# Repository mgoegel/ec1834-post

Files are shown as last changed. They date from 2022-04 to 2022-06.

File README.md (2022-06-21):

# Robotron EC1834 POST 60h (and not only port 60) ISA card

Anleitung in [Deutsch](README-DE.md)

In this project I would like to introduce you to an ISA Port 60h card for the EC1834.

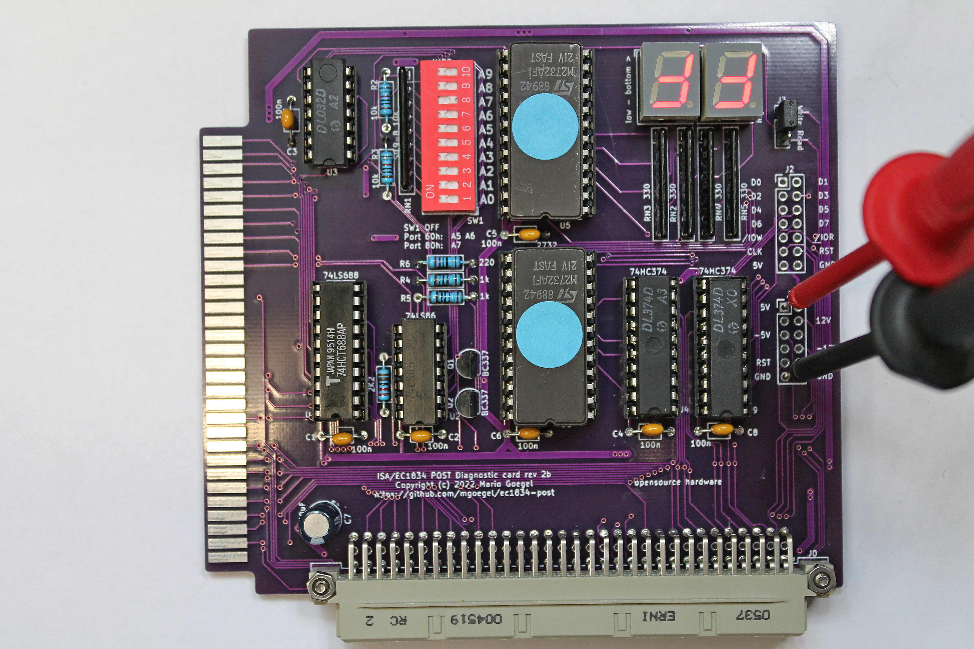
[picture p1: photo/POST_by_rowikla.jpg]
POST Platine


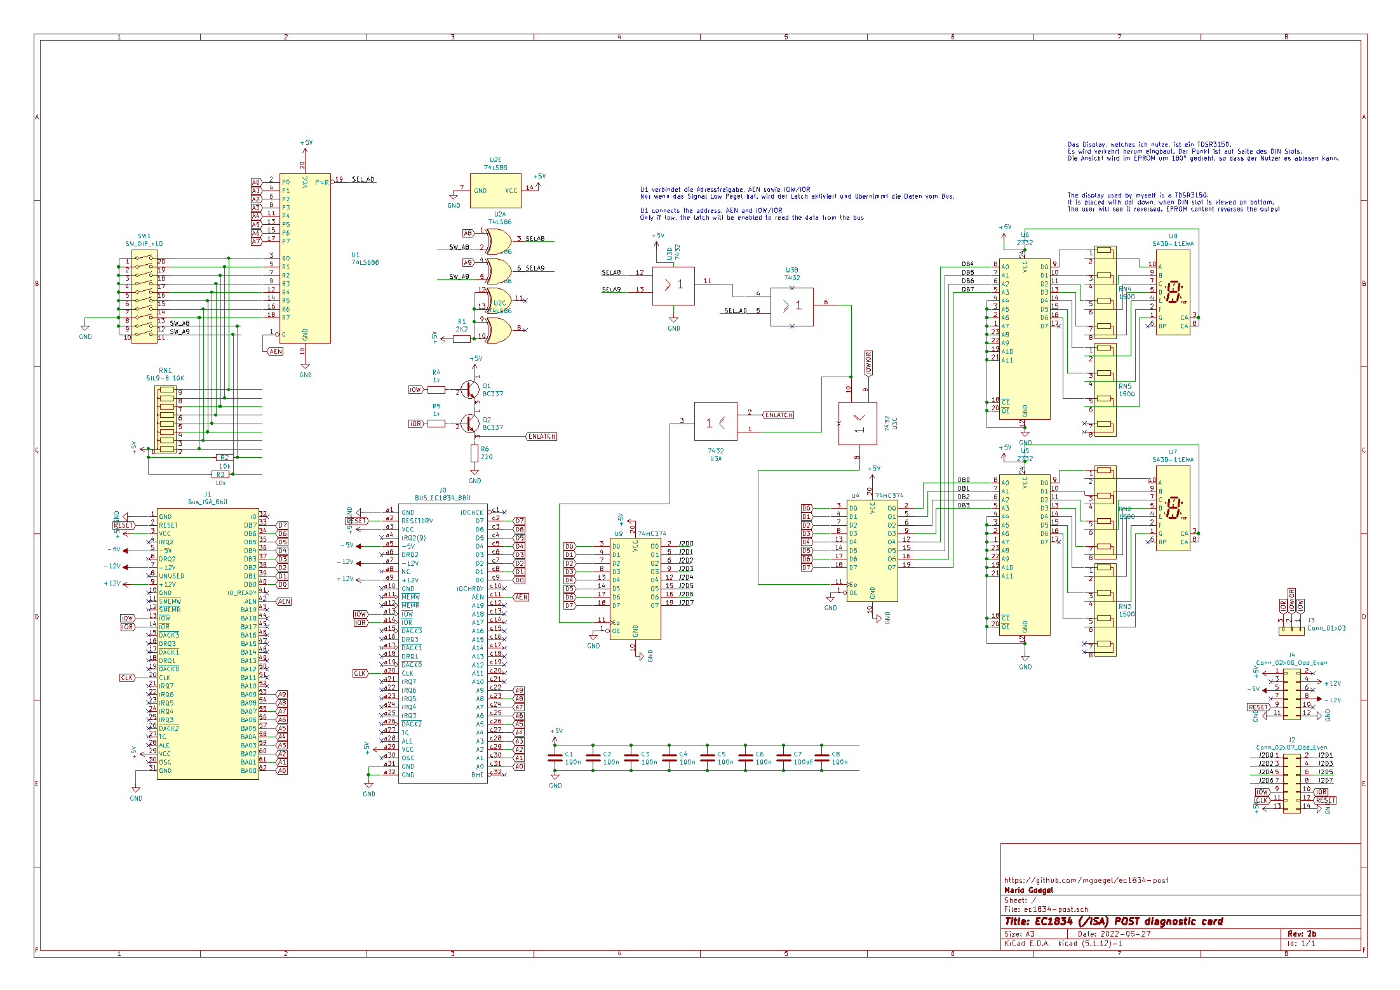
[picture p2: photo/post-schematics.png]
POST Schema


This project was inspired by:
https://bbright.tripod.com/information/postcard.htm
and by the ELV 1995-04 ISA-BIOS-POST Karte

## Description

### Decoding
The board uses 2 EPROMS for decoding the bus byte to the two 7 segment LED displays.
There may be better ways to do it (BCD to 7seg hex encoder or PAL ICs). Both techniques are obsolete and not/hardly available (as the used 2732/27C32 EPROMs are).
But to keep it as simple as possible, the EPROMs are the solution.

### Configuration
To support 74LS series ICs (the 74LS688), I used only pull up mechanisms for the configuration.
So the address lines NOT wanted, have to be switched **ON** at the DIP switch 
(which is - by the way - prepared to be replaced by a 2x10 PIN header),
when the address is to be defined.
For jumpers - these have to be set then.

Example:

* Adress 0x80 - Lines A0-A6,A8-A9 need to be set to **ON**; A7 to **OFF**
* Adress 0x60 - Lines A0-A4,A7-A9 must be **ON**; A5,A6 have to be **OFF**

The address range is configurable from 0x000-0x3ff

The display can be configured, to display read requests, instead of write requests. The Jumper J3 needs to be set to "Read".
Default should be "Write".

### Connectors
The board has 2 feature connectors.
The power connector J4 shall to be used later for a power monitoring. It provides access to all voltage (+5V, -5V, +12V, -12V, GND) lines on the ISA BUS.

Connector J2 provides easy access for a Logic analyzer. The bus data presents read and write access to IO ports on the configured port.
The ongoing transaction can be monitored on the /IOR or /IOW line, which is active low, depending on the bus transaction.

J0 can be installed as a DIN41612 64pin (a+c) connector, as no access to the 16bit data bus is needed.

## BOM

| Ref | Value |
|-----|---|
| C1  | 100n |
| C2  | 100n |
| C3  | 100n |
| C4  | 100n |
| C5  | 100n |
| C6  | 100n |
| C7  | 100uF |
| C8  | 100n |
| J0  | DIN 41612C 64(a+c) or 96 pin (abc) <br />female 90° THT connector  |
| J2  | Conn_02x07_Odd_Even |
| J3  | Conn_01x03 |
| J4  | Conn_02x06_Odd_Even |
| Q1  | BC337 |
| Q2  | BC337 |
| R1  | 2K2 |
| R2  | 10k |
| R3  | 10k |
| R4  | 1k |
| R5  | 1k |
| R6  | 220 |
| RN1 | SIL9-8 10K |
| RN2 | SIL5-4 1,5K or 4x1,5K R |
| RN3 | SIL5-4 1,5K or 4x1,5K R |
| RN4 | SIL5-4 1,5K or 4x1,5K R |
| RN5 | SIL5-4 1,5K or 4x1,5K R |
| SW1 | SW_DIP_x10 |
| U1  | 74LS688 |
| U2  | 74LS86 |
| U3  | 7432 |
| U4  | 74HC374 |
| U5  | 2732 |
| U6  | 2732 |
| U7  | SA39-11EWA |
| U8  | SA39-11EWA |
| U9  | 74HC374 |

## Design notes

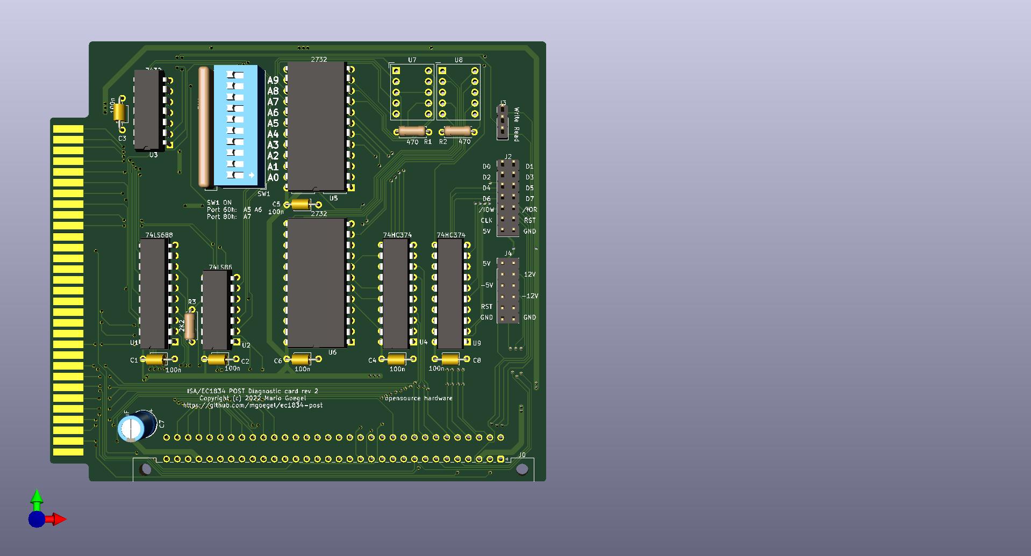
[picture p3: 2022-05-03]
photo/ec1834-post.jpg

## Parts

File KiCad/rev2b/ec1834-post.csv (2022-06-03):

Source: | F:\OneDrive\Projekte\EC1834-POST\KiCad\rev2b\ec1834-post.sch
Date: | 03.06.2022 20:12:01
Tool: | Eeschema (5.1.12)-1
Component Count: | 36
Ref | Value | Footprint | Datasheet | Manufacturer | Vendor
C1 | 100n | Capacitor_THT:C_Axial_L3.8mm_D2.6mm_P7.50mm_Horizontal | ~
C2 | 100n | Capacitor_THT:C_Axial_L3.8mm_D2.6mm_P7.50mm_Horizontal | ~
C3 | 100n | Capacitor_THT:C_Axial_L3.8mm_D2.6mm_P7.50mm_Horizontal | ~
C4 | 100n | Capacitor_THT:C_Axial_L3.8mm_D2.6mm_P7.50mm_Horizontal | ~
C5 | 100n | Capacitor_THT:C_Axial_L3.8mm_D2.6mm_P7.50mm_Horizontal | ~
C6 | 100n | Capacitor_THT:C_Axial_L3.8mm_D2.6mm_P7.50mm_Horizontal | ~
C7 | 100uF | Capacitor_THT:CP_Radial_D6.3mm_P2.50mm | ~
C8 | 100n | Capacitor_THT:C_Axial_L3.8mm_D2.6mm_P7.50mm_Horizontal | ~
J0 | BUS_EC1834_8Bit | Connector_DIN:DIN41612_C_3x32_Male_Horizontal_THT
J1 | Bus_ISA_8bit | Connector_PCBEdge:ISA-8BIT-XT-IDE | https://en.wikipedia.org/wiki/Industry_Standard_Architecture
J2 | Conn_02x07_Odd_Even | Connector_PinHeader_2.54mm:PinHeader_2x07_P2.54mm_Vertical | ~
J3 | Conn_01x03 | Connector_PinHeader_2.54mm:PinHeader_1x03_P2.54mm_Vertical | ~
J4 | Conn_02x06_Odd_Even | Connector_PinHeader_2.54mm:PinHeader_2x06_P2.54mm_Vertical | ~
Q1 | BC337 | Package_TO_SOT_THT:TO-92_Inline | https://diotec.com/tl_files/diotec/files/pdf/datasheets/bc337.pdf
Q2 | BC337 | Package_TO_SOT_THT:TO-92_Inline | https://diotec.com/tl_files/diotec/files/pdf/datasheets/bc337.pdf
R1 | 2K2 | Resistor_THT:R_Axial_DIN0207_L6.3mm_D2.5mm_P10.16mm_Horizontal | ~
R2 | 10k | Resistor_THT:R_Axial_DIN0207_L6.3mm_D2.5mm_P10.16mm_Horizontal | ~
R3 | 10k | Resistor_THT:R_Axial_DIN0207_L6.3mm_D2.5mm_P10.16mm_Horizontal | ~
R4 | 1k | Resistor_THT:R_Axial_DIN0207_L6.3mm_D2.5mm_P10.16mm_Horizontal | ~
R5 | 1k | Resistor_THT:R_Axial_DIN0207_L6.3mm_D2.5mm_P10.16mm_Horizontal | ~
R6 | 220 | Resistor_THT:R_Axial_DIN0207_L6.3mm_D2.5mm_P10.16mm_Horizontal | ~
RN1 | SIL9-8 10K | Resistor_THT:R_Array_SIP9 | http://www.vishay.com/docs/31509/csc.pdf
RN2 | 330 | Resistor_THT:R_Array_SIP8 | http://www.vishay.com/docs/31509/csc.pdf
RN3 | 330 | Resistor_THT:R_Array_SIP8 | http://www.vishay.com/docs/31509/csc.pdf
RN4 | 330 | Resistor_THT:R_Array_SIP8 | http://www.vishay.com/docs/31509/csc.pdf
RN5 | 330 | Resistor_THT:R_Array_SIP8 | http://www.vishay.com/docs/31509/csc.pdf
SW1 | SW_DIP_x10 | Button_Switch_THT:SW_DIP_SPSTx10_Slide_9.78x27.58mm_W7.62mm_P2.54mm | ~
U1 | 74LS688 | Package_DIP:DIP-20_W7.62mm | http://www.ti.com/lit/gpn/sn74LS688
U2 | 74LS86 | Package_DIP:DIP-14_W7.62mm | 74xx/74ls86.pdf
U3 | 7432 | Package_DIP:DIP-14_W7.62mm
U4 | 74HC374 | Package_DIP:DIP-20_W7.62mm | https://www.ti.com/lit/ds/symlink/cd74hct374.pdf
U5 | 2732 | Package_DIP:DIP-24_W15.24mm | https://downloads.reactivemicro.com/Electronics/ROM/2732%20EPROM.pdf
U6 | 2732 | Package_DIP:DIP-24_W15.24mm | https://downloads.reactivemicro.com/Electronics/ROM/2732%20EPROM.pdf
U7 | SA39-11EWA | Display_7Segment:Sx39-1xxxxx | http://www.kingbrightusa.com/images/catalog/SPEC/sa39-11ewa.pdf
U8 | SA39-11EWA | Display_7Segment:Sx39-1xxxxx | http://www.kingbrightusa.com/images/catalog/SPEC/sa39-11ewa.pdf
U9 | 74HC374 | Package_DIP:DIP-20_W7.62mm | https://www.ti.com/lit/ds/symlink/cd74hct374.pdf

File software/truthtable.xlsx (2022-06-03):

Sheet: XOR - rev2
 |  |  |  |  |  |  |  | hex | dez | A0-A7
 |  |  |  |  |  |  | IO: | 180 | 384 | 128
 |  |  |  |  | DIP OFF=1 |  | IO-BUS: | 180 | 384 | 128
 | Description | Signal |  | Signal 2 |  | XOR
 | ENLATCH | /IOR | 1 | /IOW | 1 | 0
 | SELA8 | A8 | 1 | DIPSW A8 | 1 | 0
 | SELA9 | A9 | 0 | DIPSW A9 | 0 | 0 | JMPR-IOR or IOW |  | IOW | 1
 |  |  |  |  |  | OR
 | U3.11 | SELA8 | 0 | SELA9 | 0 | 0
 | U3.6 | U3.11 =G15 | 0 | SEL_AD | 0 | 0
 | U3.8 | ENLATCH | 0 | U3.6 | 0 | 0
jmpr | JUMPER.IORW | IOR | 1 | ENLATCH | 0 | 1
 | U4.CLOCK | U3.8 | 0 | JUMPER.IORW | 1 | 1
 | U9.CLOCK |  |  |  |  | 0

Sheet: rev3
 |  |  |  |  |  |  |  | hex | dez | A0-A7
 |  |  |  |  |  |  | IO: | 180 | 384 | 128
 |  |  |  |  | DIP OFF=1 |  | IO-BUS: | 180 | 384 | 128
 | Description | Signal |  | Signal 2 |  | NAND
 | ENLATCH | /IOR | 1 | /IOW | 1 | 0
 | SELA8 | A8 | 1 | DIPSW A8 | 1 | 0
 | SELA9 | A9 | 0 | DIPSW A9 | 0 | 1
 | /SELA8 | SELA8 | 0 | SELA8 | 0 | 1 | JMPR-IOR or IOW |  | IOR | 1
 | /SELA9 | SELA9 | 1 | SELA9 | 1 | 0
 |  |  |  |  |  | OR
 | U3.11 | /SELA8 | 1 | /SELA9 | 0 | 1
 | U3.6 | U3.11 | 1 | SEL_AD | 0 | 1
 | U3.8 | ENLATCH | 0 | U3.6 | 1 | 1
jmpr | JUMPER.IORW | IOR | 1 | IOW | 1 | 1
 |  |  |  |  |  | NAND
 | U4.CLOCK | U3.8 | 1 | JUMPER.IORW | 0 | 1

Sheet: Tabelle3
Latech enable logic: |  |  | required: falling edge
* | Address selection
 |  | A0-A7 | SEL_AD | LOW ACT | OR
 |  | A8,A9 | SELA8,SELA9 |  | 2x NAND, 1x NAND for Invert
* | Read or Write selection
 | U4 | IOR or IOW - jumper selected
 |  |  | jumper | LOW ACT | w
 | U9 | IOR or IOW
 |  |  | OR | LOW ACT | OR
 | A8 - SW_A8

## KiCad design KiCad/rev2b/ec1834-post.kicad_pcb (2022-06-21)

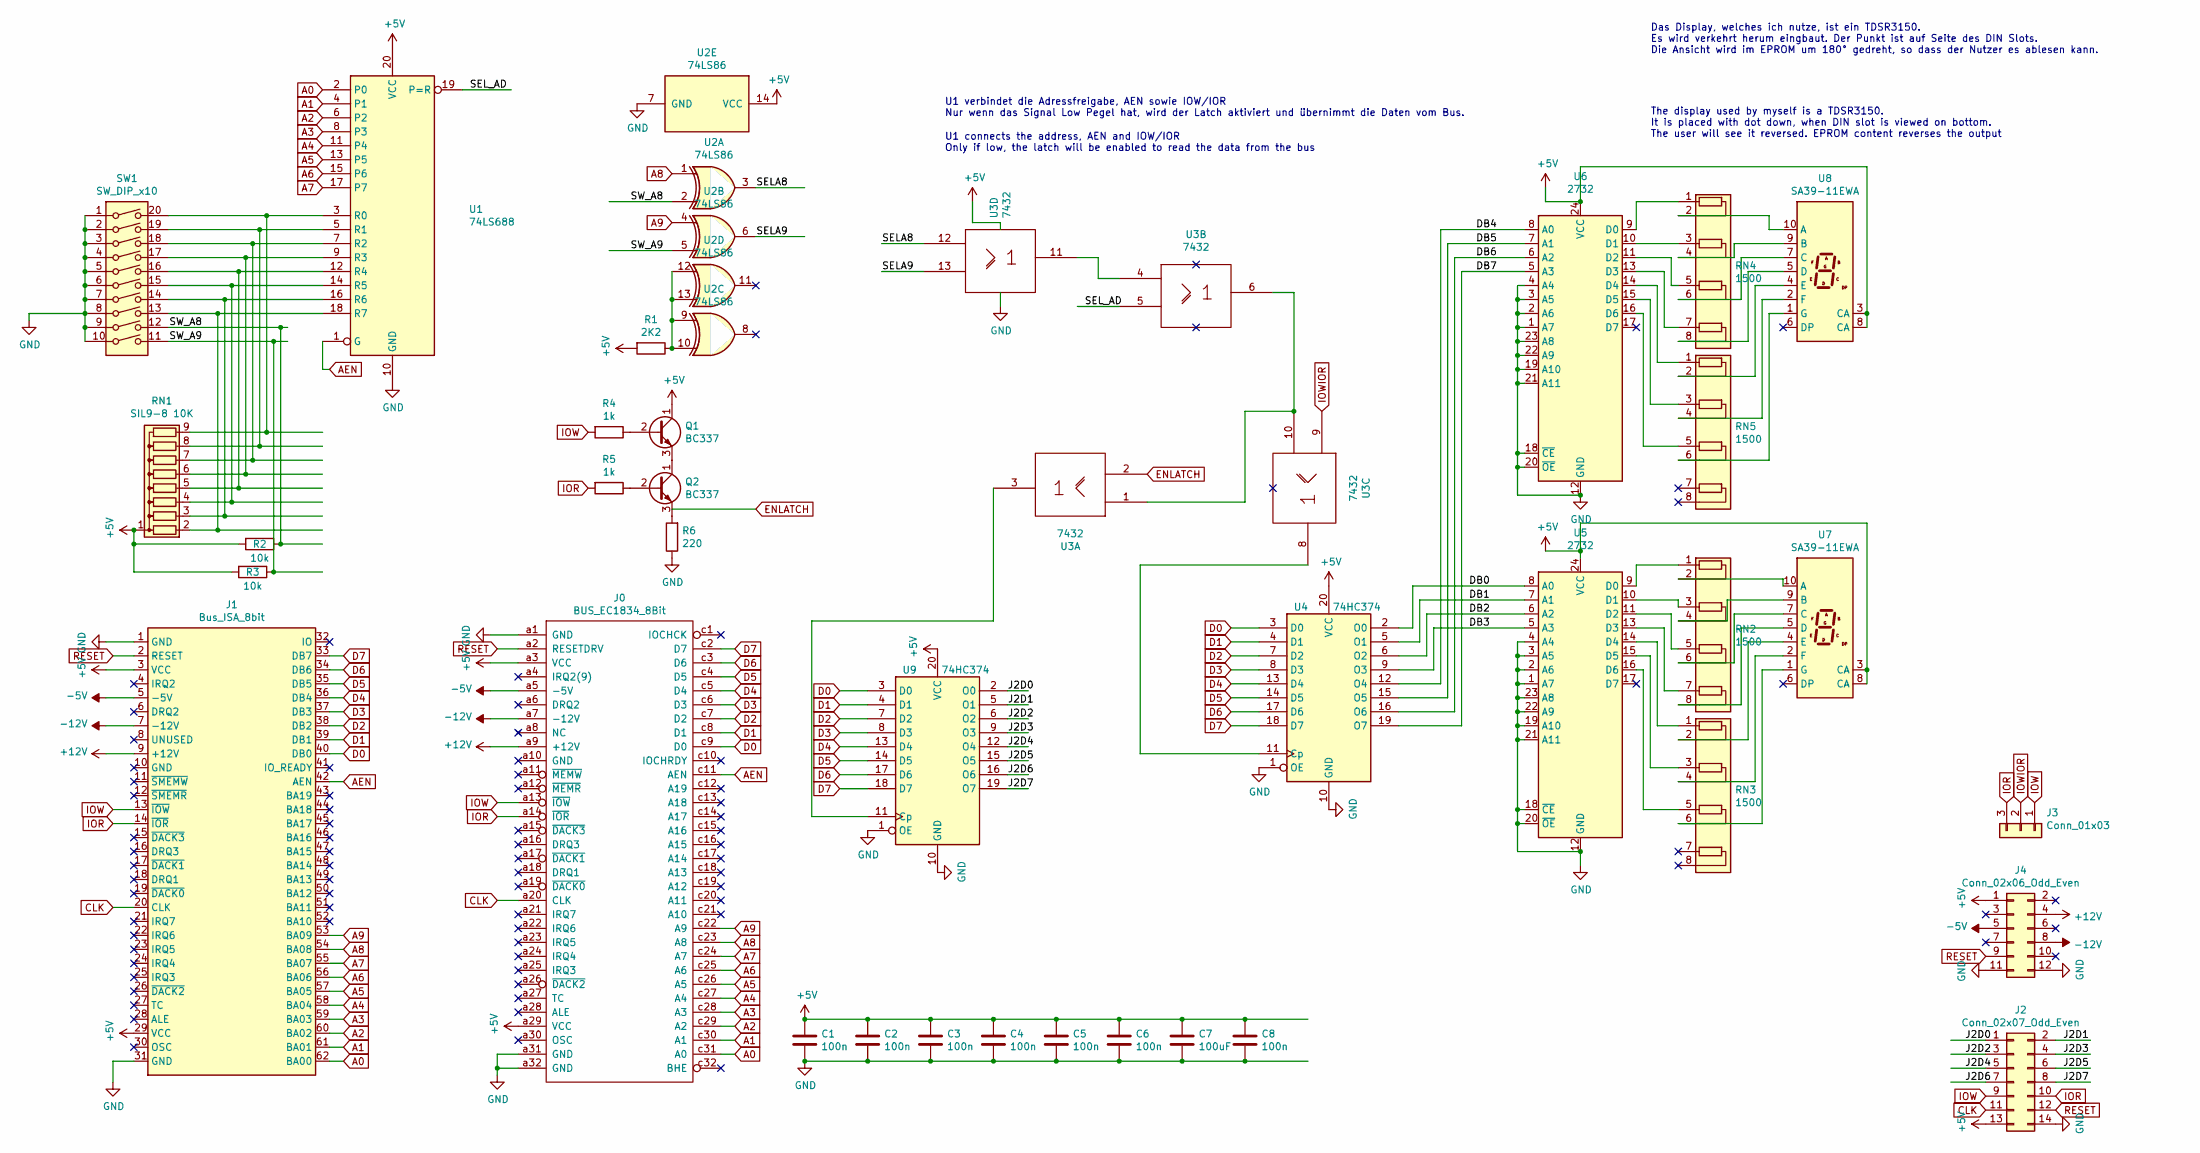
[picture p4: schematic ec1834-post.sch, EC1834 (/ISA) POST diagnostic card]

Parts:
C1, C2, C3, C4, C5, C6, C8: 100n; C_Axial_L3.8mm_D2.6mm_P7.50mm_Horizontal
C7: 100uF; CP_Radial_D6.3mm_P2.50mm
J0: BUS_EC1834_8Bit; DIN41612_C_3x32_Male_Horizontal_THT
J1: Bus_ISA_8bit; ISA-8BIT-XT-IDE
J2: Conn_02x07_Odd_Even; PinHeader_2x07_P2.54mm_Vertical
J3: Conn_01x03; PinHeader_1x03_P2.54mm_Vertical
J4: Conn_02x06_Odd_Even; PinHeader_2x06_P2.54mm_Vertical
Q1, Q2: BC337; TO-92_Inline
R1: 2K2; R_Axial_DIN0207_L6.3mm_D2.5mm_P10.16mm_Horizontal
R2, R3: 10k; R_Axial_DIN0207_L6.3mm_D2.5mm_P10.16mm_Horizontal
R4, R5: 1k; R_Axial_DIN0207_L6.3mm_D2.5mm_P10.16mm_Horizontal
R6: 220; R_Axial_DIN0207_L6.3mm_D2.5mm_P10.16mm_Horizontal
RN1: SIL9-8 10K; R_Array_SIP9
RN2, RN3, RN4, RN5: 1500; R_Array_SIP8
SW1: SW_DIP_x10; SW_DIP_SPSTx10_Slide_9.78x27.58mm_W7.62mm_P2.54mm
U1: 74LS688; DIP-20_W7.62mm
U2: 74LS86; DIP-14_W7.62mm
U3: 7432; DIP-14_W7.62mm
U4, U9: 74HC374; DIP-20_W7.62mm
U5, U6: 2732; DIP-24_W15.24mm
U7, U8: SA39-11EWA; Sx39-1xxxxx

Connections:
+5V: C1.1, C2.1, C3.1, C4.1, C5.1, C6.1, C7.1, C8.1, J0.a3 (VCC), J0.a29 (VCC), J1.3 (VCC), J1.29 (VCC), J2.13, J4.1, Q1.1 (C), R1.2, R2.2, R3.2, RN1.1 (common), U1.20 (VCC), U2.14 (VCC), U3.14 (Vcc), U4.20 (VCC), U5.24 (VCC), U6.24 (VCC), U7.3 (CA), U7.8 (CA), U8.3 (CA), U8.8 (CA), U9.20 (VCC)
+12V: J0.a9 (+12V), J1.9 (+12V), J4.4
-5V: J0.a5 (-5V), J1.5 (-5V), J4.5
-12V: J0.a7 (-12V), J1.7 (-12V), J4.8
/DB0: U4.2 (O0), U5.8 (A0)
/DB1: U4.5 (O1), U5.7 (A1)
/DB2: U4.6 (O2), U5.6 (A2)
/DB3: U4.9 (O3), U5.5 (A3)
/DB4: U4.12 (O4), U6.8 (A0)
/DB5: U4.15 (O5), U6.7 (A1)
/DB6: U4.16 (O6), U6.6 (A2)
/DB7: U4.19 (O7), U6.5 (A3)
/J2D0: J2.1, U9.2 (O0)
/J2D1: J2.2, U9.5 (O1)
/J2D2: J2.3, U9.6 (O2)
/J2D3: J2.4, U9.9 (O3)
/J2D4: J2.5, U9.12 (O4)
/J2D5: J2.6, U9.15 (O5)
/J2D6: J2.7, U9.16 (O6)
/J2D7: J2.8, U9.19 (O7)
/SELA8: U2.3, U3.12
/SELA9: U2.6, U3.13
/SEL_AD: U1.19 (P=R), U3.5
/SW_A8: R2.1, SW1.12, U2.2
/SW_A9: R3.1, SW1.11, U2.5
A0: J0.c31 (A0), J1.62 (BA00), U1.2 (P0)
A1: J0.c30 (A1), J1.61 (BA01), U1.4 (P1)
A2: J0.c29 (A2), J1.60 (BA02), U1.6 (P2)
A3: J0.c28 (A3), J1.59 (BA03), U1.8 (P3)
A4: J0.c27 (A4), J1.58 (BA04), U1.11 (P4)
A5: J0.c26 (A5), J1.57 (BA05), U1.13 (P5)
A6: J0.c25 (A6), J1.56 (BA06), U1.15 (P6)
A7: J0.c24 (A7), J1.55 (BA07), U1.17 (P7)
A8: J0.c23 (A8), J1.54 (BA08), U2.1
A9: J0.c22 (A9), J1.53 (BA09), U2.4
AEN: J0.c11 (AEN), J1.42 (AEN), U1.1 (G)
CLK: J0.a20 (CLK), J1.20 (CLK), J2.11
D0: J0.c9 (D0), J1.40 (DB0), U4.3 (D0), U9.3 (D0)
D1: J0.c8 (D1), J1.39 (DB1), U4.4 (D1), U9.4 (D1)
D2: J0.c7 (D2), J1.38 (DB2), U4.7 (D2), U9.7 (D2)
D3: J0.c6 (D3), J1.37 (DB3), U4.8 (D3), U9.8 (D3)
D4: J0.c5 (D4), J1.36 (DB4), U4.13 (D4), U9.13 (D4)
D5: J0.c4 (D5), J1.35 (DB5), U4.14 (D5), U9.14 (D5)
D6: J0.c3 (D6), J1.34 (DB6), U4.17 (D6), U9.17 (D6)
D7: J0.c2 (D7), J1.33 (DB7), U4.18 (D7), U9.18 (D7)
ENLATCH: U3.2
GND: C1.2, C2.2, C3.2, C4.2, C5.2, C6.2, C7.2, C8.2, J0.a1 (GND), J0.a31 (GND), J0.a32 (GND), J1.1 (GND), J1.31 (GND), J2.14, J4.11, J4.12, R6.1, SW1.1, SW1.2, SW1.3, SW1.4, SW1.5, SW1.6, SW1.7, SW1.8, SW1.9, SW1.10, U1.10 (GND), U2.7 (GND), U3.7 (Gnd), U4.1 (OE), U4.10 (GND), U5.1 (A7), U5.2 (A6), U5.3 (A5), U5.4 (A4), U5.12 (GND), U5.18 (~CE), U5.19 (A10), U5.20 (~OE), U5.21 (A11), U5.22 (A9), U5.23 (A8), U6.1 (A7), U6.2 (A6), U6.3 (A5), U6.4 (A4), U6.12 (GND), U6.18 (~CE), U6.19 (A10), U6.20 (~OE), U6.21 (A11), U6.22 (A9), U6.23 (A8), U9.1 (OE), U9.10 (GND); also elsewhere on the board
IOR: J0.a14 (~IOR), J1.14 (~IOR), J2.10, J3.3, R5.2
IOW: J0.a13 (~IOW), J1.13 (~IOW), J2.9, J3.1, R4.2
IOWIOR: J3.2, U3.9
unnamed: Q1.2 (B), R4.1
unnamed: Q1.3 (E), Q2.1 (C)
unnamed: Q2.2 (B), R5.1
unnamed: Q2.3 (E), R6.2
unnamed: R1.1, U2.9, U2.10, U2.12, U2.13
unnamed: RN1.2 (R1), SW1.13, U1.18 (R7)
unnamed: RN1.3 (R2), SW1.14, U1.16 (R6)
unnamed: RN1.4 (R3), SW1.15, U1.14 (R5)
unnamed: RN1.5 (R4), SW1.16, U1.12 (R4)
unnamed: RN1.6 (R5), SW1.17, U1.9 (R3)
unnamed: RN1.7 (R6), SW1.18, U1.7 (R2)
unnamed: RN1.8 (R7), SW1.19, U1.5 (R1)
unnamed: RN1.9 (R8), SW1.20, U1.3 (R0)
unnamed: RN2.1 (R1.1), U5.9 (D0)
unnamed: RN2.2 (R1.2), U7.10 (A)
unnamed: RN2.3 (R2.1), U5.10 (D1)
unnamed: RN2.4 (R2.2), U7.9 (B)
unnamed: RN2.5 (R3.1), U5.11 (D2)
unnamed: RN2.6 (R3.2), U7.7 (C)
unnamed: RN2.7 (R4.1), U5.13 (D3)
unnamed: RN2.8 (R4.2), U7.5 (D)
unnamed: RN3.1 (R1.1), U5.14 (D4)
unnamed: RN3.2 (R1.2), U7.4 (E)
unnamed: RN3.3 (R2.1), U5.15 (D5)
unnamed: RN3.4 (R2.2), U7.2 (F)
unnamed: RN3.5 (R3.1), U5.16 (D6)
unnamed: RN3.6 (R3.2), U7.1 (G)
unnamed: RN4.1 (R1.1), U6.9 (D0)
unnamed: RN4.2 (R1.2), U8.10 (A)
unnamed: RN4.3 (R2.1), U6.10 (D1)
unnamed: RN4.4 (R2.2), U8.9 (B)
unnamed: RN4.5 (R3.1), U6.11 (D2)
unnamed: RN4.6 (R3.2), U8.7 (C)
unnamed: RN4.7 (R4.1), U6.13 (D3)
unnamed: RN4.8 (R4.2), U8.5 (D)
unnamed: RN5.1 (R1.1), U6.14 (D4)
unnamed: RN5.2 (R1.2), U8.4 (E)
unnamed: RN5.3 (R2.1), U6.15 (D5)
unnamed: RN5.4 (R2.2), U8.2 (F)
unnamed: RN5.5 (R3.1), U6.16 (D6)
unnamed: RN5.6 (R3.2), U8.1 (G)
unnamed: U3.1, U3.6, U3.10
unnamed: U3.3, U9.11 (Cp)
unnamed: U3.8, U4.11 (Cp)
unnamed: U3.4, U3.11
RESET: J0.a2 (RESETDRV), J1.2 (RESET), J2.12, J4.9

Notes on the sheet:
U1 connects the address, AEN and IOW/IOR Only if low, the latch will be enabled to read the data from the bus
The display used by myself is a TDSR3150. It is placed with dot down, when DIN slot is viewed on bottom. The user will see it reversed. EPROM content reverses the output
Das Display, welches ich nutze, ist ein TDSR3150. Es wird verkehrt herum eingbaut. Der Punkt ist auf Seite des DIN Slots. Die Ansicht wird im EPROM um 180° gedreht, so dass der Nutzer es ablesen kann.
U1 verbindet die Adressfreigabe, AEN sowie IOW/IOR Nur wenn das Signal Low Pegel hat, wird der Latch aktiviert und übernimmt die Daten vom Bus.

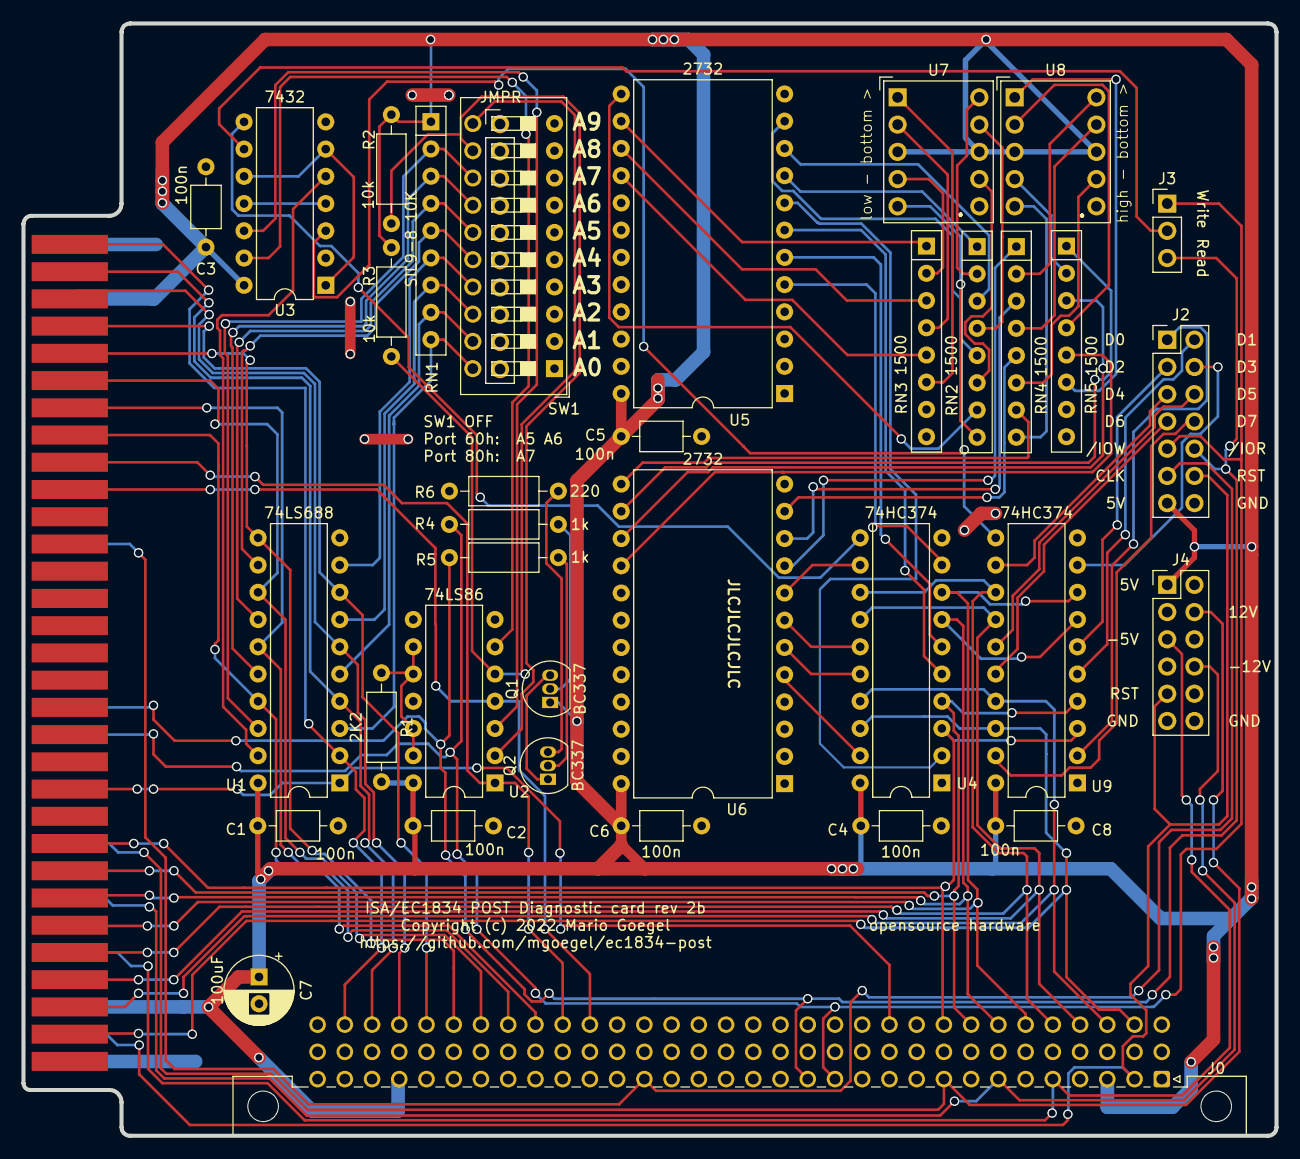
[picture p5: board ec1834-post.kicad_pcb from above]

Board: 2 copper layers, 116.9 x 103.7 mm, 37 parts (0 on the bottom side), 95 nets.

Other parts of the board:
JMPR: JMPR; PinHeader_1x10_P2.54mm_Vertical

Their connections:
GND: JMPR.1, JMPR.2, JMPR.3, JMPR.4, JMPR.5, JMPR.6, JMPR.7, JMPR.8, JMPR.9, JMPR.10; also elsewhere on the board

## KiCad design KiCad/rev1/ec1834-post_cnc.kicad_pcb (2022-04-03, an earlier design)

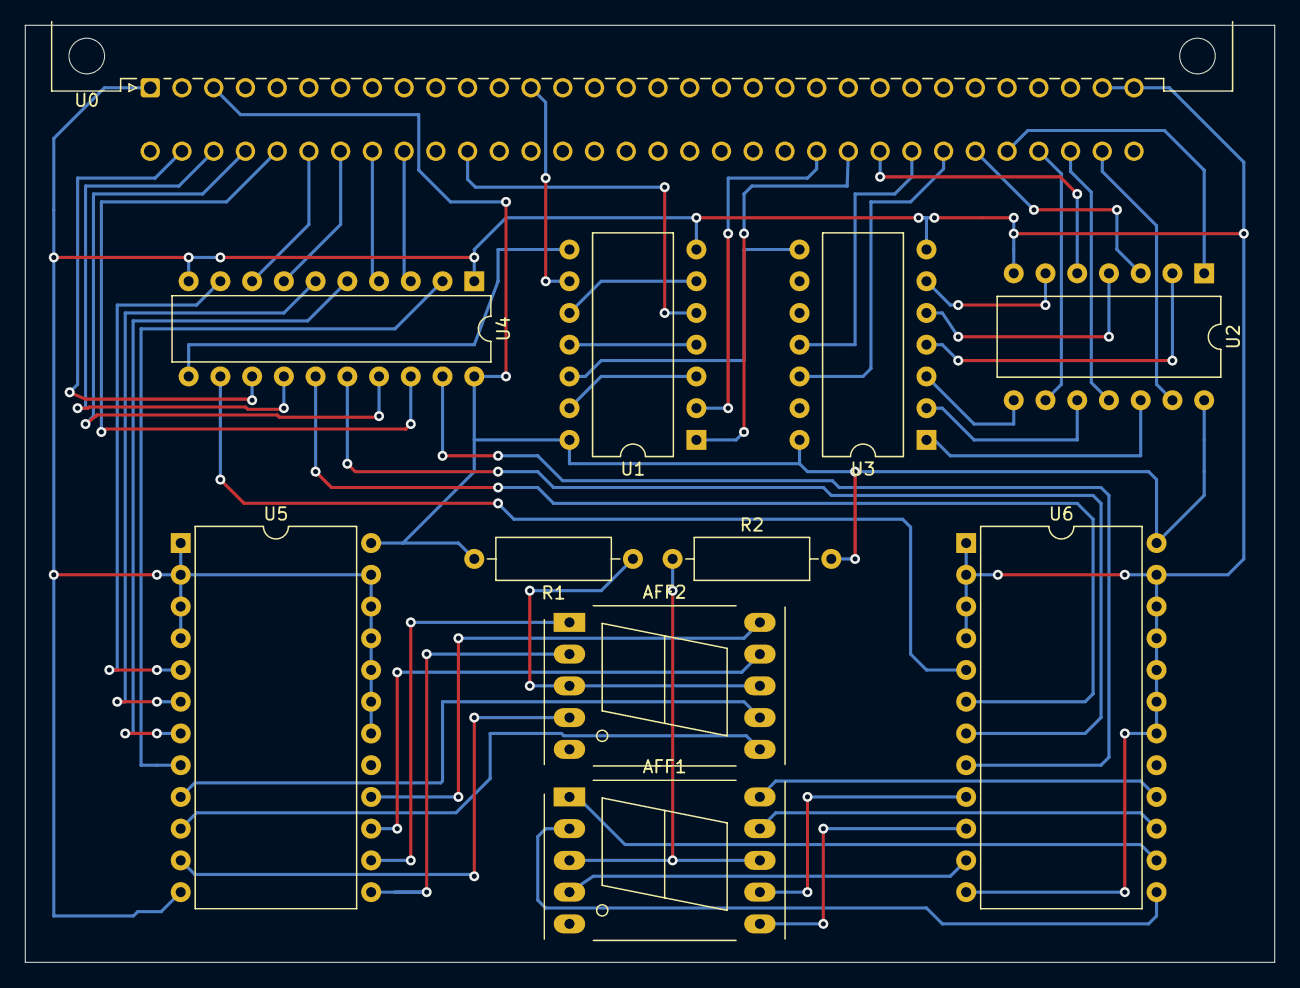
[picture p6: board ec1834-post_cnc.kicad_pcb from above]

Board: 2 copper layers, 100.0 x 75.0 mm, 11 parts (0 on the bottom side), 57 nets.

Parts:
AFF1, AFF2: LTS-6960HR; 7SegmentLED_LTS6760_LTS6780
R1, R2: 470; R_Axial_DIN0309_L9.0mm_D3.2mm_P12.70mm_Horizontal
U0: BUS_EC1834_8Bit; DIN41612_C_2x32_Male_Horizontal_THT
U1: 7432; DIP-14_W10.16mm
U2: 74HC04; DIP-14_W10.16mm
U3: 7430; DIP-14_W10.16mm
U4: 74HC374; DIP-20_W7.62mm
U5, U6: 2732; DIP-24_W15.24mm

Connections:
+5V: R1.2, R2.2, U0.a3, U1.14, U2.14, U3.14, U4.20, U5.24, U6.24
A0: U0.c31, U2.13
A1: U0.c30, U2.11
A2: U0.c29, U2.9
A3: U0.c28, U2.1
A4: U0.c27, U2.3
A5: U0.c26, U3.12
A6: U0.c25, U3.11
A7: U0.c24, U2.5
A8: U0.c23, U1.1
A9: U0.c22, U1.2
AEN: U0.c11, U1.5
D0: U0.c9, U4.3
D1: U0.c8, U4.4
D2: U0.c7, U4.7
D3: U0.c6, U4.8
D4: U0.c5, U4.18
D5: U0.c4, U4.17
D6: U0.c3, U4.14
D7: U0.c2, U4.13
GND: U0.a1, U0.a31, U0.a32, U1.7, U2.7, U3.7, U4.1, U4.10, U5.1, U5.2, U5.3, U5.4, U5.12, U5.18, U5.19, U5.20, U5.21, U5.22, U5.23, U6.1, U6.2, U6.3, U6.4, U6.12, U6.18, U6.19, U6.20, U6.21, U6.22, U6.23
IOW: U0.a13, U1.9
unnamed: AFF1.1, U6.14
unnamed: AFF1.2, U6.13
unnamed: AFF1.3, AFF1.8, R2.1
unnamed: AFF1.4, U6.11
unnamed: AFF1.6, U6.10
unnamed: AFF1.7, U6.9
unnamed: AFF1.9, U6.15
unnamed: AFF1.10, U6.16
unnamed: AFF2.1, U5.14
unnamed: AFF2.2, U5.13
unnamed: AFF2.3, AFF2.8, R1.1
unnamed: AFF2.4, U5.11
unnamed: AFF2.6, U5.10
unnamed: AFF2.7, U5.9
unnamed: AFF2.9, U5.15
unnamed: AFF2.10, U5.16
unnamed: U1.8, U4.11
unnamed: U1.6, U1.10
unnamed: U1.4, U1.11
unnamed: U1.12, U3.8
unnamed: U1.3, U1.13
unnamed: U2.2, U3.4
unnamed: U2.4, U3.5
unnamed: U2.6, U3.6
unnamed: U2.8, U3.3
unnamed: U2.10, U3.2
unnamed: U2.12, U3.1
unnamed: U4.2, U5.8
unnamed: U4.5, U5.7
unnamed: U4.6, U5.6
unnamed: U4.9, U5.5
unnamed: U4.12, U6.5
unnamed: U4.15, U6.6
unnamed: U4.16, U6.7
unnamed: U4.19, U6.8

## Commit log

2022-03-22 Schema completed Building PCB...
    [ec1834-post.kicad_pcb, ec1834-post.sch]
2022-04-03 Rework from CNC layout (which would be too close for 3018) to better layout for JLCPCB
    [ec1834-post-B_Adhes.gbr, ec1834-post-B_CrtYd.gbr, ec1834-post-B_Cu.gbr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]
2022-04-25 Added EPROM content Fixed DIP footprints (too wide) Added ISA BUS/Edge
    [ec1834-post.sch]
2022-04-30 New revision routing still in progress
    [ec1834-post.kicad_pcb, ec1834-post.sch]
2022-05-03 Rebuild of PCB is done
    [ec1834-post.kicad_pcb, ec1834-post.sch]
2022-05-03 Updated schema, fixed wrong footprint
    [ec1834-post.kicad_pcb, ec1834-post.sch]
2022-05-04 reorganized directory
    [ec1834-post-B_Adhes.gbr, ec1834-post-B_CrtYd.gbr, ec1834-post-B_Cu.gbr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]
2022-06-03 Updated scheme to rev2 Update EPROM binaries Updated PCB to rev2 and new foot prints Added better documentation
    [EPROM_rev2b.xlsx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]
2022-06-20 Some schematics beautify actions Added schematics as PNG Typo fixed in BOM
    [ec1834-post.kicad_pcb, ec1834-post.sch]
2022-06-21 Fixed schematics and PCB (RN2-RN5 value changed to 1K5 R) Added an image Added german documentation
    [ec1834-post.kicad_pcb, ec1834-post.sch]

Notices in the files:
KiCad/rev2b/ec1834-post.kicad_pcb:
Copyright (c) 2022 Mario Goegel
